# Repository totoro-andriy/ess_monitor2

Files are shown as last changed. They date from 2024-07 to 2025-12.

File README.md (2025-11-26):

# LG ESS Monitoring Tool

### Схема

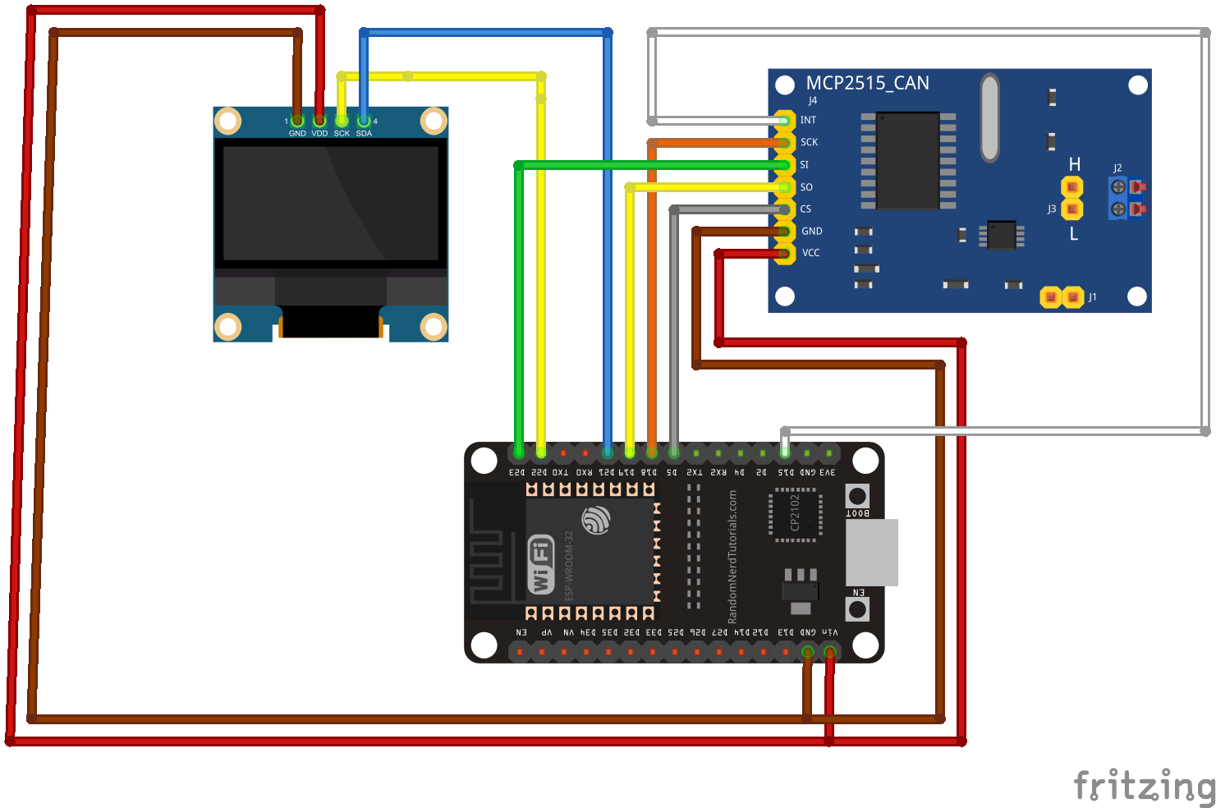
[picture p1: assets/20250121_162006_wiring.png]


**1. esp32 wroom devkit v1**
**2. mcp2515 can-bus module**
**3. 0.96" 128x64 oled display i2c**
**4. USB кабель для esp32**
**5. Ethernet кабель**
**6. Зарядний пристрий USB 5v**

Усі три модулі працють від спільного живлення 5в яке приходить із USB роз'єму. CAN Модуль зєднаний із мікроконтроллером шиною **SPI** а Дизплей за допомогою шини **I2C**.

### Корпус

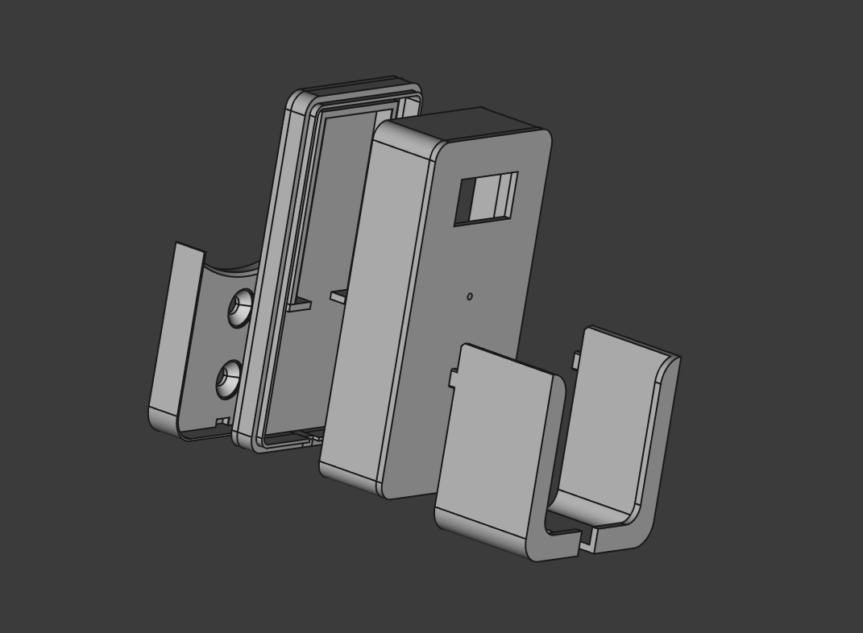
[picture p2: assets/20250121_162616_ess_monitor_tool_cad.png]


файли для друку знаходяться у папці STL

## Опис

Блок адаптації був створений для уможливлення роботи батарей LG ESS (CAN) 48V із довільними інвертормаи.

Вся суть роботи полягає в тому що батареї потрібно отримувати keep_alive пакети від інвертора.
У випадку коли такі пакети не будуть отримані батарея відключиться із помилкою за 20 хв.
Блок адаптація посилає цей пакет в кан шину батареї кожну секунду завдяки чому батарея працює в тому режимі в якому це було предбачино виробником.

Батарея у свою чергу отримуючи сигнал від Інвертора починає надсилати інформацію про її стан здоров'я, заряду та інше.
що ми можемо відобразити на дисплеї та у інші способи  про які нижче.

***Блок Адаптації не вносить змін в алгоритм батареї. Більше того! Механізмів як вплинути на роботу батареї(наприклад виключити її) не було знайдено під час процесу аналізу та розбору протоколу***

### Протестовано наступні типи батарей:

#### LG ESS

**EM048126P3S7**

**EM048063P3S5**

**EM048063P3S4**

#### LG RESU

**RESU 13**

**RESU 6.5**

***Увага високовольтні версії із індексом H на даний момент не підтримуються!***

#### JK SMART Inverter BMS

так як бмс мімікрує під протокол Pylontech встановлено випадки успішного відаленого моніторингу батареї через ess_monitor

### Протестовано наступні марки інверторів в автоматичному режимі роботи Lithium BMS:

Deye - (працює в режимі Lithium, повноцінна робота як батарея PYLONTECH)
LuxPower - (батарея заблокована в режимі Lithium потрібно власника інвертора як добровольця для тестів)

## Інформація отримана із батареї

Щойно отримано інформацію з батареї вона починає відображатися на дисплеї блоку адаптації
весь **програмний код працює таким чином що відображається остання інформація яку було отримано.** іншими словами блок буде відображати останню помилку і стан справ навіть коли батарея вимкнулася аварійно що дозволить швидко зробити налагодження системи.

***У разі виникнення незрозумілих виключень батареї потрібно заживити блок адаптації ESS Monitoring Tool із окремого джерела живлення (PowerBank тощо).***

## Дисплей

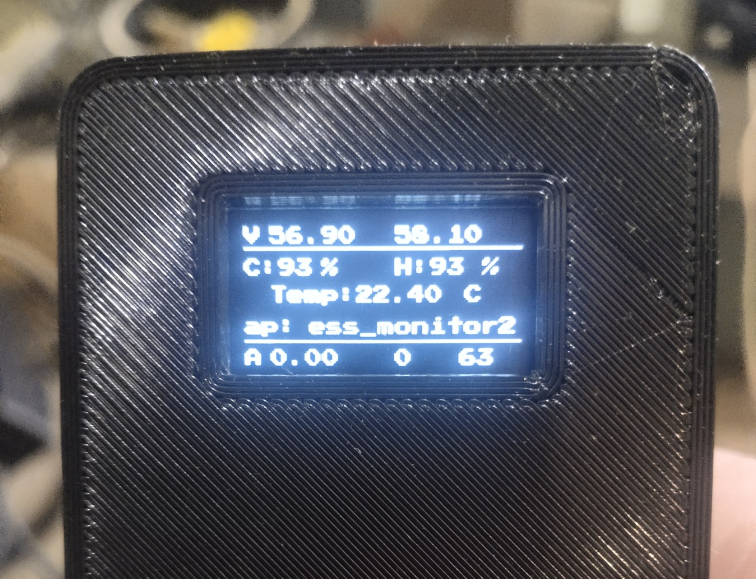
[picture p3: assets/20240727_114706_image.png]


### Voltage

| **V** | Поточна напруга батареї | Максимально допустима напруга батареї |
| --- | --- | --- |

### State of Charge / Health

| **C:** | Поточний заряд батареї | Поточний стан здоров'я батареї |
| --- | --- | --- |

***Зверніть увагу що "здоров'я" вираховується контролером батареї і на нашу думку він не відображає фізичного стану батареї. На фото до прикладу батарея не досягнувши напруги повного заряду заблокувала заряд (що свідчить про критичний розбаланс елементів) але контролре всерівно показує 93% здоровя. також із нашого досвіду цей параметр ніяк не відслідковує вздуття елементів. та інших проблем із батареєю!***

### Temperature

По центрі дисплею вказано поточну температуру батареї.
Це досить важливий параметр за яким варто слідкувати адже температура може значно перевищувати навколишню при інтенсивній роботі елементів. Тому слідкуйте аби ваша батарея не нагрівалася надмірно (вище 45 градусів). також критично важливо не заряджати батарею високими струмами коли температура набуває від'ємних значень.

### System Status

Над другою горизонтальною лінією розміщену строку поточного статусу системи. У випадку коли помилок від батареї не зафіксовано строка відображає поточний стан **Wifi**

| **ap:** | назва віфі точки доступу |
| --- | --- |

По замовчуванню блок адаптації ESS Monitor Tool працює в режимі точки доступу **ess-monitor** та паролем **12345678** увійшовши до цієї безпровідної мережі можливо налаштування додаткових опцій завдяки вбудованому **Web Порталу**.

у випадку коли блок адаптації успішно під'єднався до вашої безпровідної мережі буде відображено поточну IP адресу!

| **ip:** | 192.168.0.100 |
| --- | --- |

### BMS Error

Стан віфі мережі буде приховано у випадку коли батарея передасть код помилки батареї
***Власне батарея постійно передає код помилки із значенням нуль але показувати надпис що помилок немає нашу думку немає змісту***

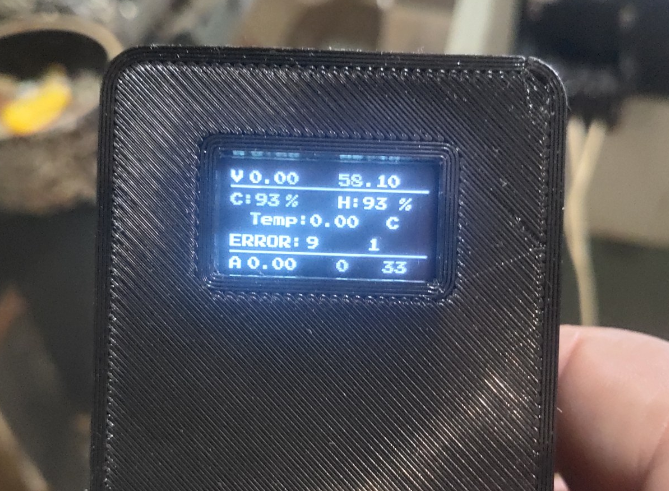
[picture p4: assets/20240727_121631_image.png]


Помилка складається із 2 цифр перша це помилка Аварії при якій батарея буде вимикатися
друга цифра відповідає за Помилку Уваги (висока напруга, температура, тощо) сама по собі не призводить до виключення батареї але часто передує іншій критичній

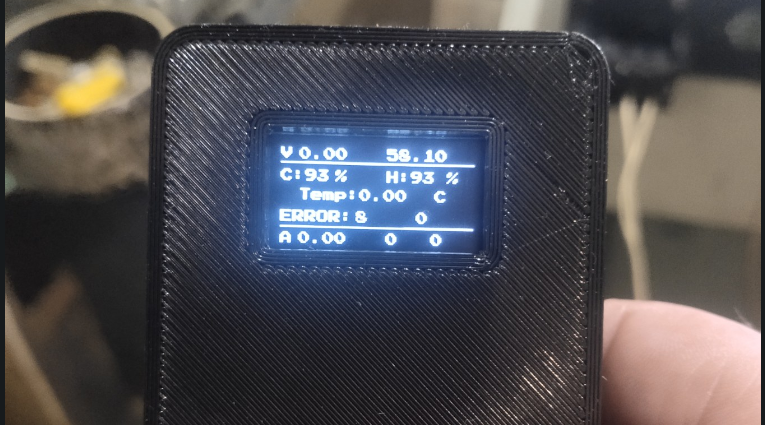
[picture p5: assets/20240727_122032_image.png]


| **ERROR:** | Помилка | Опис |
| --- | --- | --- |
| **ERROR:** | 9 1 | Критичне Розбалансування елементів |
| **ERROR:** | 8 0 | Перевищення робочих лімітів батареї по струму! |

***У разі невиконання лімітів батареї інвертором батарея вимкнеться!***

Нам невідомі коди помилок які було задіяно виробником тому ми не можемо надати весь список кодів, працюємо із тим що знаємо.

### Battery Current and Limmits

Остання строка відображає поточні ліміти батареї по струму і поточне навантаження

| **A** | Поточний струм | Ліміт ампер по заряду | Ліміт ампер по розраду |
| --- | --- | --- | --- |

***Якщо поточний струм вказано із від'ємним знаком - батарея виснажується. Додатне - заряджає***

Ліміти батареї міняються динамічно як правило за наступною схемою.

Чим більше батарея розряджена тим більше допустимий струм заряду а струм заряду навпаки зменшується чим більше батарея наближається до 0% і навпаки чим більше батарея наблизилася до 100% заряду тим менший струм заряду вона декларує.

## Web Portal

### ESS

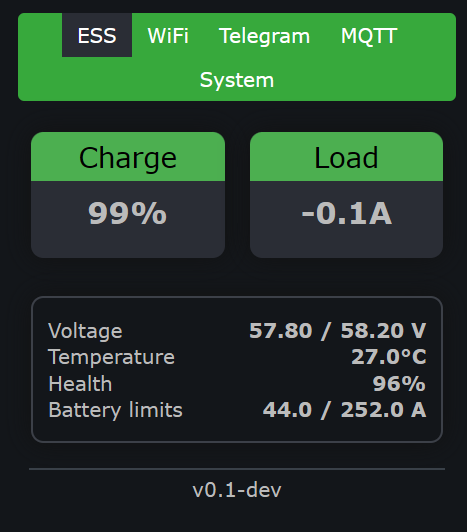
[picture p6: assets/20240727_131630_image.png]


За допомогою веб порталу можна переглянути стан батареї.
Загалом перша вкладка повністю повторює функціонал OLED дисплею і дозволяє пререглянути поточний заряд та ліміти батареї

### Wifi

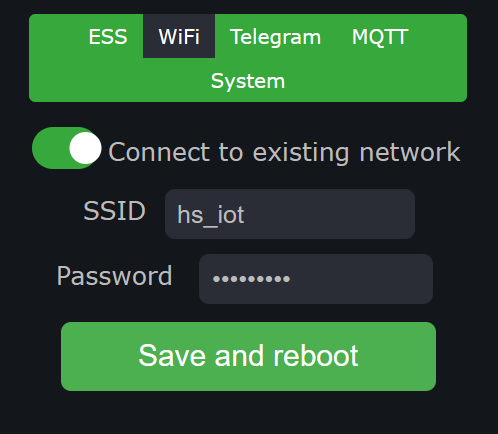
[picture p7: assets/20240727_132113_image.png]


дане меню дозволяє налаштувати під'єднання до домашньої віфі мережі (перевести в блок адаптації в режим вайфай клієнта)

Уважно увівши назву віфі мережі та пароль натисніть клавішу **Save and Reboot**
***Траплялися декілька випадків коли після спроби підключення блоку до віфі мережі він переставав працювати повністю, допомагає повторна прошивка контролера, старайтеся не використовувати в мережі CamelCase або інші спецсимволи, бо ця проблема не є до кінця дослідженна***

після перезавантаження блок адаптації буде пробувати під'єднуватися до мережі і якщо він буде успішним то в строці статусу буде вказано поточну айпі адресу в іншому випадку блок  адаптації перейде назад в режим точки доступу

***Підключення до вайфай обов'язкове для використання функціоналу Сповіщення в Telegram та Home Assistant***

### Telegram

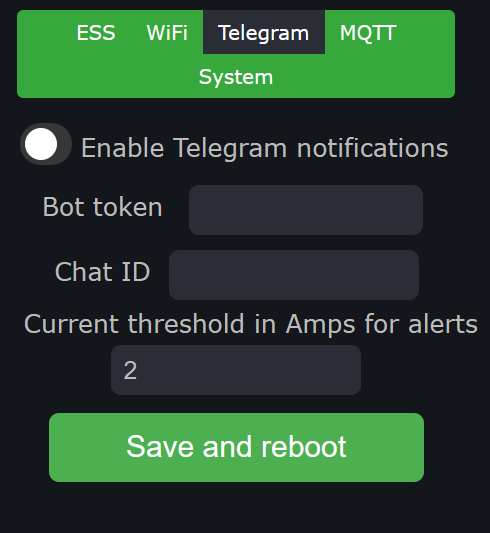
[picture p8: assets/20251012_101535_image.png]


#### Для роботи сповіщень потрібно створити бота та отримати токен та айді чату

- Створити бота: [@BotFather](https://t.me/BotFather) → команда `/newbot` → отримай **BOT_TOKEN**.
- [@userinfobot](https://t.me/userinfobot) — показує твій `id`;
- або відкрий у браузері після того, як написав щось боту:

  ```
  https://api.telegram.org/bot<BOT_TOKEN>/getUpdates
  ```

  У відповіді знайди поле `chat":{"id":123456789}` — це і є твій Chat ID.
- Для груп або каналів Chat ID зазвичай має вигляд `-100xxxxxxxxxx`.

#### Алгоритм роботи сповіщень у Telegram

Система постійно вимірює струм, який проходить через батарею, і на основі його значення визначає поточний режим живлення:

 - Charging — батарея заряджається (струм позитивний, тече в батарею);
 - Discharging — батарея розряджається (струм негативний, живить навантаження);
 - Balance — ні заряджання, ні розряджання (струм близький до нуля).

Кожні 5 секунд виконується перевірка поточного струму.
Якщо режим змінився з попереднього (наприклад, з Charging на Discharging), — надсилається повідомлення у Telegram.

##### Параметр CurrentThreshold

CurrentThreshold — це порогове значення струму (у амперах), яке визначає, коли вважати систему такою, що перейшла з одного стану в інший.

Цей параметр потрібен, щоб відфільтрувати дрібні коливання струму, які виникають природно під час стабільної роботи (наприклад, ±0.5 А).
Тільки коли струм перевищує цей поріг, вважається, що відбувся реальний перехід режиму:

##### Коли надходять сповіщення

Бот надсилає повідомлення тільки при зміні стану між Charging ↔ Discharging.
Наприклад:

💡 Електроживлення відновлено — коли після розряджання система почала заряджатися.

🕯️ Перехід на живлення від батареї — коли навпаки, пропала мережа й система почала розряджатися.

У стані Balance повідомлення не надсилаються.

##### Команди користувача

/status — показує поточні дані батареї (заряд, струм, напруга, температура, стан здоров’я).

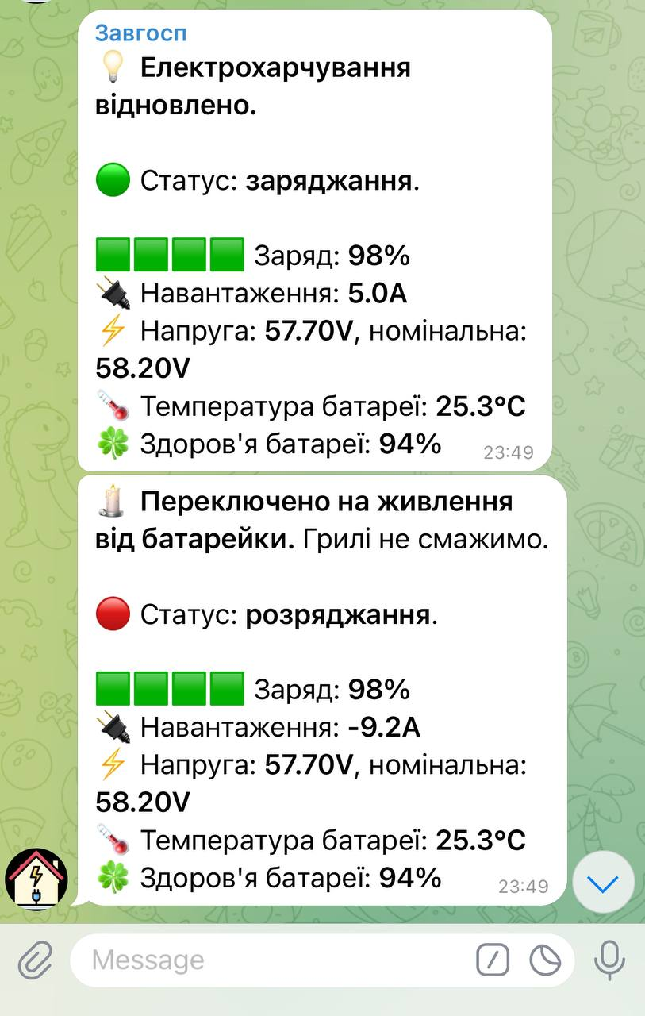
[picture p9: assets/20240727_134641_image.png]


### MQTT

З останіьою ревізією прошивки для блоку адаптації стала можливість роботи батареї в ролі сенсора для [Home Assistant](https://www.home-assistant.io/) це дозволило зручно контролювати роботу батареї через застосунок у сматрфоні та налаштовувати довільні автоматизації вашого розумного дому (такі як виключення некритичних споживачів через розумні розетки у разі вимкнень світла або сповіщень через улюблений канал звязку)

Для увімкнення функції потрібно ввести адресу MQTT брокера і перезавантажити блок адаптації

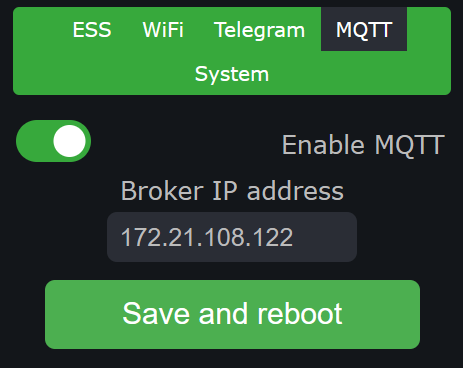
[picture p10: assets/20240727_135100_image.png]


***MQTT агент реалізований без застосування шифрування тому в Home Assistant потрібно встановити брокер [EMQX](https://www.emqx.com/en)***

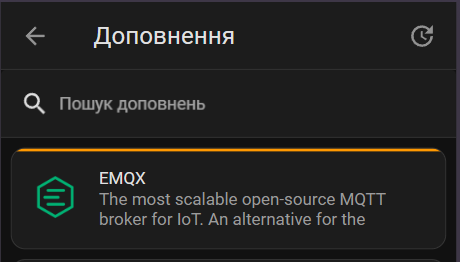
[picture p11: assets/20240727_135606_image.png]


Якщо все було налаштовано вірно в Home Assistant з'явиться новий сенсор

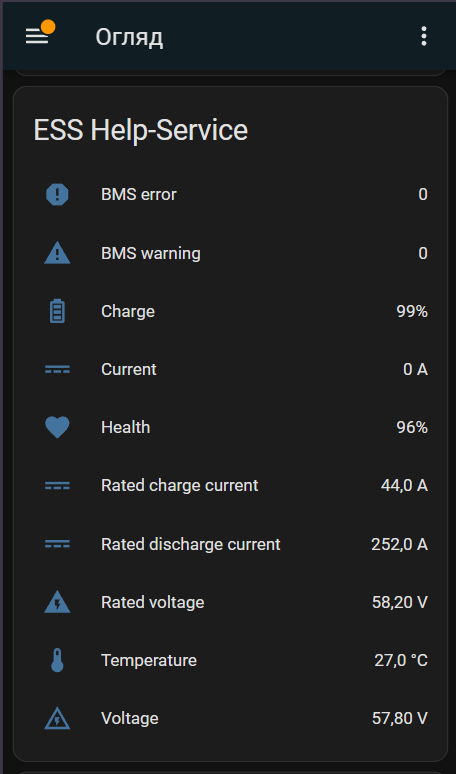
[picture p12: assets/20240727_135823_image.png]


тепер ви можете створювати власні інформаційні панелі які відповідають вашим вимогам

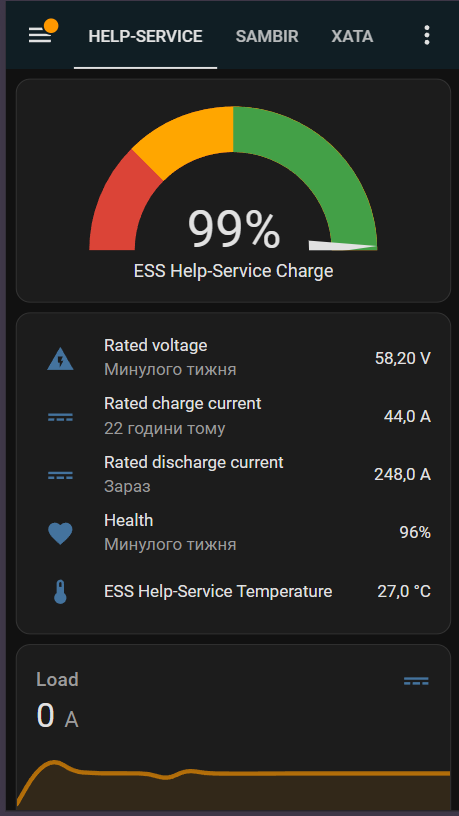
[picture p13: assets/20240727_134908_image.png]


### System

Ця вкладка дозволяє визначити чи система працює стабільно чи не перезаванатажується і чи хороший сигнал вайфай

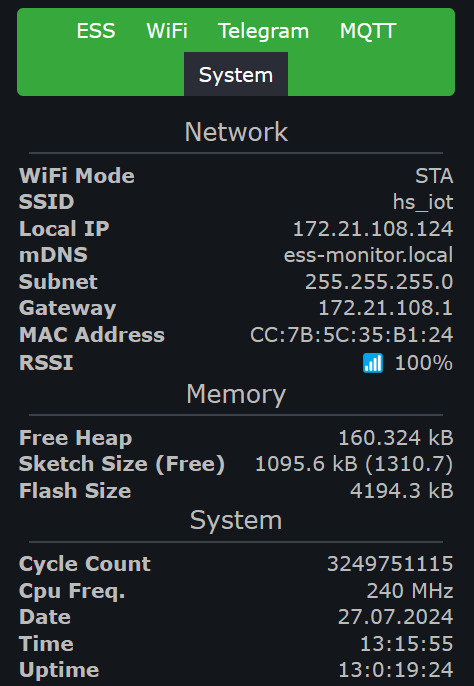
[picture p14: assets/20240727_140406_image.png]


ми використовуємо його для відладки

## Контакти

Якщо у вас є бажання долучитися до розробки цього програмного забезпечення, надати інформацію для цієї інструкції або просто отримати допомогу і консультацію можете [зв'язатися зі мною через месенджер telegram @tetor](https://t.me/tetor)

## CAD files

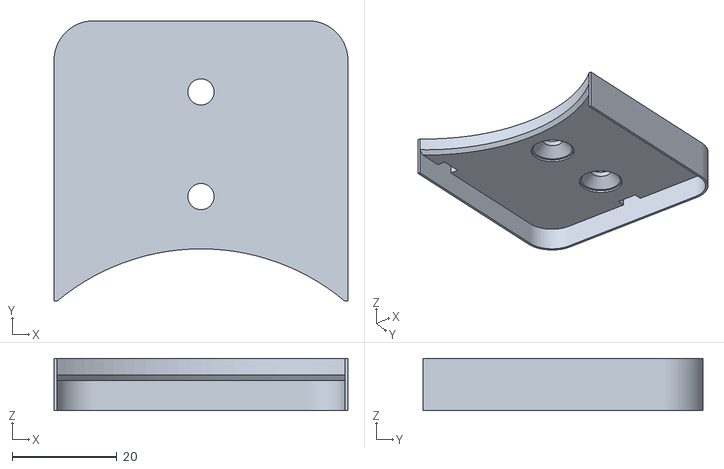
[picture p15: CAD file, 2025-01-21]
STL/LG RESU_ESS Monitor tool-HolderLower.stl
56.2 x 53.6 x 10.0

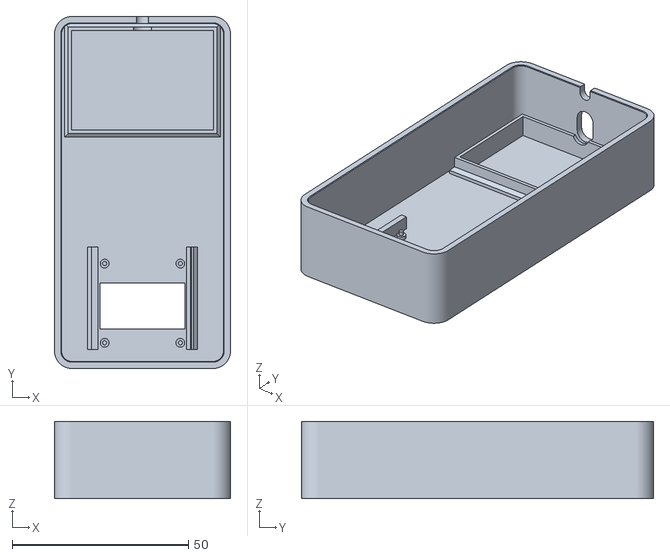
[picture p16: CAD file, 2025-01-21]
STL/LG RESU_ESS Monitor tool-ess_case.stl
50.0 x 100.0 x 22.0

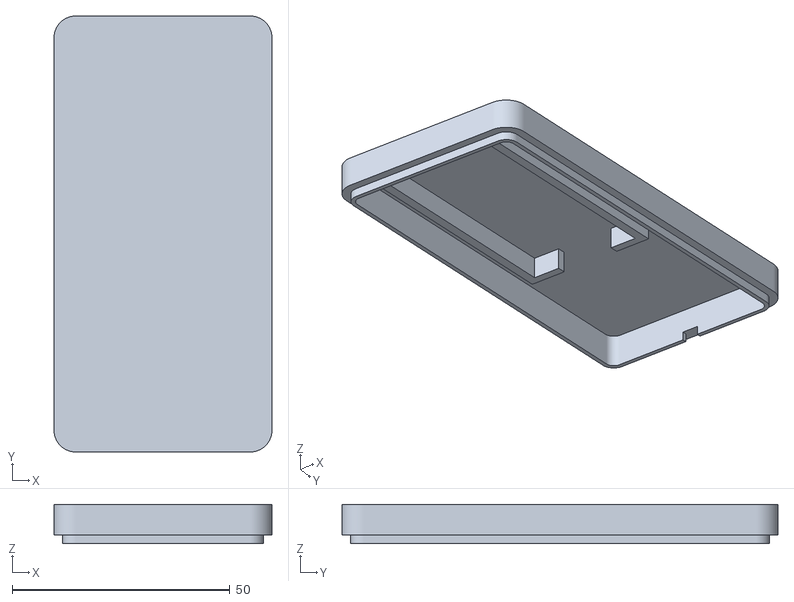
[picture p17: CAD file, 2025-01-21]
STL/LG RESU_ESS Monitor tool-Cover for ESP.stl
50.0 x 100.0 x 9.00

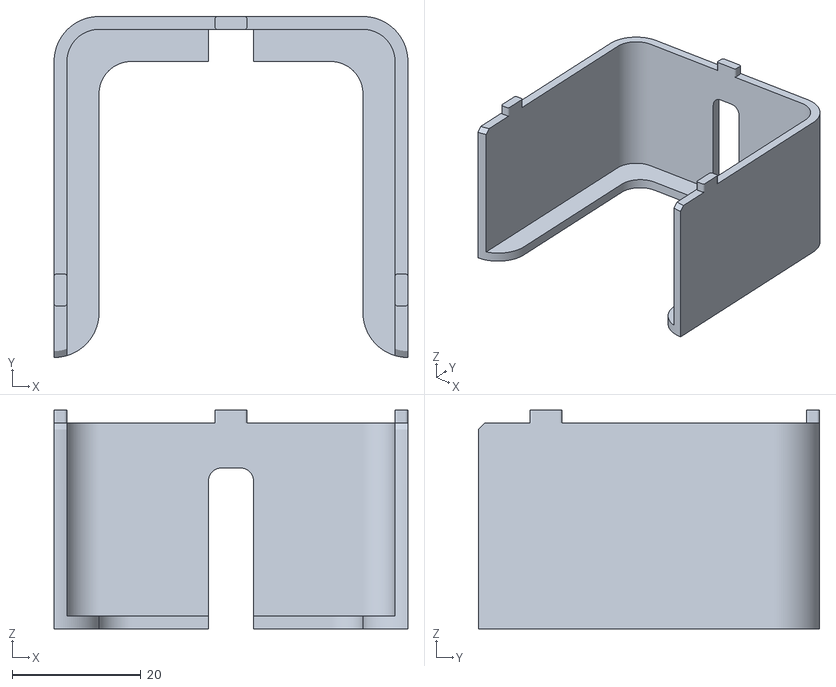
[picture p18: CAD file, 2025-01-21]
STL/LG RESU_ESS Monitor tool-HolderUpper.stl
55.0 x 53.0 x 34.0

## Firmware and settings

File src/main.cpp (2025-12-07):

#include "can.h"
#include "hass.h"
#include "lcd.h"
#include "tg.h"
#include "types.h"
#include "web.h"
#include <Arduino.h>
#include <IPAddress.h>
#include <Preferences.h>
#include <WiFi.h>
#include <WiFiMulti.h>


WiFiMulti wifiMulti;

Preferences Pref;
Config Cfg;
volatile EssStatus Ess;

void initConfig();

bool wifiEverConnected = false;

bool needRestart = false;

bool initWiFi();
void logBatteryState();

void setup() {
  Serial.begin(115200);

  initConfig();

  if (initWiFi()) {
    if (Cfg.mqttEnabled) {
      HASS::begin(1, 1);
    }
    if (Cfg.tgEnabled) {
      TG::begin(1, 1);
    }
  }

  CAN::begin(1, 3); // TODO: wait for success for tg and hass to start
  WEB::begin(1, 1);
  LCD::begin(1, 1);
}

void loop() {
  static uint32_t previousMillis;
  uint32_t currentMillis = millis();

  // WiFi reconnection
  wifiMulti.run();

  // Every 5 seconds
  if (currentMillis - previousMillis >= 5000 * 1) {
    previousMillis = currentMillis;

    logBatteryState();

    //SoftReset
    if (needRestart){ESP.restart();};
  }
}

void initConfig() {
  Pref.begin("ess");

  Cfg.wifiSTA = Pref.getBool(CFG_WIFI_STA, Cfg.wifiSTA);
  Pref.getString(CFG_WIFI_SSID, Cfg.wifiSSID, sizeof(Cfg.wifiSSID));
  Pref.getString(CFG_WIFI_PASS, Cfg.wifiPass, sizeof(Cfg.wifiPass));

  Pref.getString(CFG_HOSTNAME, Cfg.hostname, sizeof(Cfg.hostname));

  Cfg.chargeLimit = Pref.getUChar(CFG_INVERTER_CHARGE_LIMIT, Cfg.chargeLimit);
  Cfg.dishargeLimit =
      Pref.getUChar(CFG_INVERTER_DISCHARGE_LIMIT, Cfg.dishargeLimit);

  Cfg.mqttEnabled = Pref.getBool(CFG_MQQTT_ENABLED, Cfg.mqttEnabled);
  Pref.getString(CFG_MQQTT_BROKER_IP, Cfg.mqttBrokerIp,
                 sizeof(Cfg.mqttBrokerIp));

  Cfg.tgEnabled = Pref.getBool(CFG_TG_ENABLED, Cfg.tgEnabled);
  Pref.getString(CFG_TG_BOT_TOKEN, Cfg.tgBotToken, sizeof(Cfg.tgBotToken));
  Pref.getString(CFG_TG_CHAT_ID, Cfg.tgChatID, sizeof(Cfg.tgChatID));
  Cfg.tgCurrentThreshold = Pref.getUChar(CFG_TG_CURRENT_THRESHOLD, Cfg.tgCurrentThreshold);
}

bool initWiFi() {
  if (Cfg.wifiSTA && Cfg.wifiSSID != NULL && Cfg.wifiSSID[0] != '\0') {
    Serial.printf("Connecting to %s...", Cfg.wifiSSID);

    WiFi.mode(WIFI_STA);
    WiFi.config(INADDR_NONE, INADDR_NONE, INADDR_NONE, INADDR_NONE);
    WiFi.setHostname(Cfg.hostname);

    // Reset WiFiMulti
    wifiMulti = WiFiMulti();
    wifiMulti.addAP(Cfg.wifiSSID, Cfg.wifiPass);

    uint32_t previousMillis = millis();
    while (millis() - previousMillis < 20000) {
      if (wifiMulti.run() == WL_CONNECTED) {
        Serial.println(" OK.");
        Serial.println("IP Address: " + WiFi.localIP().toString());
        Serial.printf("mDNS hostname: '%s.local'\n", Cfg.hostname);
        wifiEverConnected = true;
        return true;
      }
      delay(500);
      Serial.print(".");
    }

    Serial.println("Could not connect to WiFi network in 20 seconds.");
  }

  if (!wifiEverConnected) {
    Serial.println("Starting WiFi access point.");
    IPAddress AP_IP(192, 168, 4, 1);
    IPAddress AP_PFX(255, 255, 255, 0);
    WiFi.disconnect();
    WiFi.mode(WIFI_AP);
    WiFi.softAPConfig(AP_IP, AP_IP, AP_PFX);
    WiFi.softAP(Cfg.hostname, "12345678");
    Serial.printf("Access point SSID: '%s'\n", Cfg.hostname);
    return false;
  }

  return false;
}

void logBatteryState() {
#ifdef DEBUG
  Serial.printf("[MAIN] Load %.1f | RC %.1f/%.1f | SOC %d%% | SOH %d%% | T "
                "%.1f°C | V %.2f/%.2f\n",
                Ess.current, Ess.ratedChargeCurrent, Ess.ratedDischargeCurrent,
                Ess.charge, Ess.health, Ess.temperature, Ess.voltage,
                Ess.ratedVoltage);
#endif
}

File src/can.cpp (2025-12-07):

#include "can.h"
#include "types.h"
#include <HardwareSerial.h>
#include <SPI.h>
#include <freertos/FreeRTOS.h>
#include <freertos/task.h>
#include <mcp_can.h>
#include <stdint.h>

extern volatile EssStatus Ess;

namespace CAN {

volatile uint32_t timestamp_frame351=0;
volatile uint32_t timestamp_frame355=0;
volatile uint32_t timestamp_frame356=0;
volatile uint32_t timestamp_frame359=0;

static uint32_t last305OkMs = 0;
static const uint32_t WD_TIMEOUT_MS = 5UL * 60UL * 1000UL; // 5 хвилин

MCP_CAN can(CS_PIN);
portMUX_TYPE stateMux = portMUX_INITIALIZER_UNLOCKED;

TaskHandle_t canTaskHandle = nullptr;
void IRAM_ATTR onCanInt();

void begin(uint8_t core, uint8_t priority);
void task(void *pvParameters);
void loop();
bool initCAN();
void readCAN();
void writeCAN();
void logReadDataFrame(DataFrame *f);
// void logWriteDataFrame(DataFrame *f);
int16_t bytesToInt16(uint8_t low, uint8_t high);
void processDataFrame(DataFrame *f);
uint8_t getChargeControlByte();
DataFrame getChargeDataFrame();

bool sendFrameChecked(const DataFrame &f) {
  const uint8_t maxRetries = 3;

  for (uint8_t i = 0; i < maxRetries; i++) {
    byte rc = can.sendMsgBuf(f.id, f.dlc, (uint8_t *)f.data);
    if (rc == CAN_OK) {
      return true;
    }
    vTaskDelay(pdMS_TO_TICKS(1));
  }

#ifdef DEBUG
  Serial.printf("[CAN] ERROR: sendMsgBuf(0x%03X) failed after %u retries\n",
                f.id, maxRetries);
#endif
  return false;
}

void begin(uint8_t core, uint8_t priority) {
  xTaskCreatePinnedToCore(task, "can_task", 20000,
                          NULL, priority, &canTaskHandle, core);
}

bool initCAN() {
  if (can.begin(MCP_ANY, CAN_500KBPS, MCP_8MHZ) == CAN_OK) {
    can.setMode(MCP_NORMAL);
    pinMode(INT_PIN, INPUT_PULLUP);
    attachInterrupt(digitalPinToInterrupt(INT_PIN), CAN::onCanInt, FALLING);
    Serial.println(F("[CAN] Initializing MCP2515... OK."));
    return true;
  }
  Serial.println(F("[CAN] Initializing MCP2515... ERROR!"));
  return false;
}

void IRAM_ATTR onCanInt() {
  if (canTaskHandle == nullptr) {
    return;
  }

  BaseType_t xHigherPriorityTaskWoken = pdFALSE;
  vTaskNotifyGiveFromISR(canTaskHandle, &xHigherPriorityTaskWoken);
  if (xHigherPriorityTaskWoken == pdTRUE) {
    portYIELD_FROM_ISR();
  }
}

void task(void *pvParameters) {
  Serial.printf("[CAN] Task running in core %d.\n", (uint32_t)xPortGetCoreID());

  if (!initCAN()) {
    Serial.println("[CAN] Task exited due to init error.");
    vTaskDelete(NULL);
    return;
  }

  uint32_t previousWriteMillis = millis();

  while (1) {
    ulTaskNotifyTake(pdTRUE, pdMS_TO_TICKS(10));
    readCAN();
    uint32_t now = millis();
    if (now - previousWriteMillis >= 1000) {
      previousWriteMillis = now;
      writeCAN();
    }
  }

  Serial.println("[CAN] Task exited.");
  vTaskDelete(NULL);
}

void loop() {
  
}

void readCAN() {
  DataFrame f = {};

  while (can.checkReceive() == CAN_MSGAVAIL) {
    if (can.readMsgBuf((unsigned long *)&f.id, &f.dlc, f.data) == CAN_OK) {
      processDataFrame(&f);
    } else {
      break;
    }
  }
}

// void writeCAN() {
// DataFrame chargeFrame = getChargeDataFrame();

// // logWriteDataFrame((DataFrame *)&DF_35E);
// can.sendMsgBuf(DF_35E.id, DF_35E.dlc, (uint8_t *)DF_35E.data);
// logWriteDataFrame((DataFrame *)&DF_305);
// can.sendMsgBuf(DF_305.id, DF_305.dlc, (uint8_t *)DF_305.data);
// // logWriteDataFrame(&chargeFrame);
// can.sendMsgBuf(chargeFrame.id, chargeFrame.dlc, chargeFrame.data);
// }

// void logReadDataFrame(DataFrame *f) {
// #ifdef DEBUG
// Serial.printf("[CAN] Frame received:\t <- ID: %04x DLC: %d Data: "
//               "%02x %02x %02x %02x %02x %02x %02x %02x\n",
//               f->id, f->dlc, f->data[0], f->data[1], f->data[2], f->data[3],
//               f->data[4], f->data[5], f->data[6], f->data[7]);
// #endif
// }

// void logWriteDataFrame(DataFrame *f) {
// #ifdef DEBUG
//   Serial.printf("[CAN] Frame sent:\t -> ID: %04x DLC: %d Data: "
//                 "%02x %02x %02x %02x %02x %02x %02x %02x\n",
//                 f->id, f->dlc, f->data[0], f->data[1], f->data[2], f->data[3],
//                 f->data[4], f->data[5], f->data[6], f->data[7]);
// #endif
// }

void writeCAN() {
  DataFrame chargeFrame = getChargeDataFrame();
  (void)sendFrameChecked(DF_35E);
  if (sendFrameChecked(DF_305)) {
    last305OkMs = millis();
  } else {
  #ifdef DEBUG
    Serial.println("[CAN] WARNING: 0x305 send failed");
  #endif
  }
  if (last305OkMs != 0 && (millis() - last305OkMs > WD_TIMEOUT_MS)) {
    Serial.println("[CAN] ERROR: No successful 0x305 for 5 minutes — restarting ESP!");
    ESP.restart();
  }
  (void)sendFrameChecked(chargeFrame);
}

int16_t bytesToInt16(uint8_t low, uint8_t high) { return (high << 8) | low; }

void processDataFrame(DataFrame *f) {
  portENTER_CRITICAL(&stateMux);
  switch (f->id) {
  case 849: // 0x351 Battery Limits
    Ess.ratedVoltage = bytesToInt16(f->data[0], f->data[1]) / 10.0;
    Ess.ratedChargeCurrent = bytesToInt16(f->data[2], f->data[3]) / 10.0;
    Ess.ratedDischargeCurrent = bytesToInt16(f->data[4], f->data[5]) / 10.0;
    timestamp_frame351 = millis();
    break;
  case 853: // 0x355 Battery Health
    Ess.charge = bytesToInt16(f->data[0], f->data[1]);
    Ess.health = bytesToInt16(f->data[2], f->data[3]);
    timestamp_frame355 = millis();
    break;
  case 854: // 0x356 System Voltage, Current, Temp
    Ess.voltage = bytesToInt16(f->data[0], f->data[1]) / 100.0;
    Ess.current = bytesToInt16(f->data[2], f->data[3]) / 10.0;
    Ess.temperature = bytesToInt16(f->data[4], f->data[5]) / 10.0;
    timestamp_frame356 = millis();
    break;
  case 857: // 0x359 BMS Error
    Ess.bmsWarning = f->data[1];
    Ess.bmsError = f->data[3];
    timestamp_frame359 = millis();
    break;
  }
  portEXIT_CRITICAL(&stateMux);
}

uint8_t getChargeControlByte() {
  uint8_t res = 0;
  if (false) { // TODO: if(data.full_charge_time)
    res |= (1 << 3);
  }
  if (Ess.ratedDischargeCurrent != 0 && Ess.charge > 30) {
    // Battery allows discharging and discharge policy is ok.
    // TODO: read target discharge value from settings
    res |= (1 << 6);
  }
  if (Ess.ratedChargeCurrent != 0 && Ess.charge < 98) {
    // Battery allows charging and charge policy is ok.
    // TODO: read target charge value from settings
    res |= (1 << 7);
  }
  return res;
}

DataFrame getChargeDataFrame() {
  DataFrame f = {0x35c, 2, {getChargeControlByte(), 0x00}};
  return f;
}

} // namespace CAN

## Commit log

2024-06-18 Can bus iteration
2024-06-20 Refactor battery related logic to library; cover with tests.
2025-01-21 docs rearrange
    [LG RESU_ESS Monitor tool-Cover for ESP.stl, LG RESU_ESS Monitor tool-HolderLower.stl, LG RESU_ESS Monitor tool-HolderUpper.stl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]
2025-09-21 fix: wifi connection loss
    [main.cpp]
2025-10-14 feat: nice UX reset + fix: tgCurrentThreshold not used
    [main.cpp, tg.cpp, types.h]
2025-11-26 HASS/CAN: add per-frame timestamps + publish-once logic
2025-11-26 fix: hass volatile timestamp
    [can.cpp, hass.cpp, types.h]
2025-12-07 fix: static sensor values not updating in HA (force publish, handle expire_after)
    [can.cpp, hass.cpp, main.cpp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]
